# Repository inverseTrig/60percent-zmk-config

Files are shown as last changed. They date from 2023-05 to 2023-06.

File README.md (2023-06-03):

# 60percent

**60percent** (quite original, I know) is a 3D printed, handwired keyboard powered by [ZMK](https://zmk.dev/) inspired by the [tokyo60](https://tokyokeyboard.com/tokyo60/). If you are new to handwiring, [worry not](https://geekhack.org/index.php?topic=87689.0).

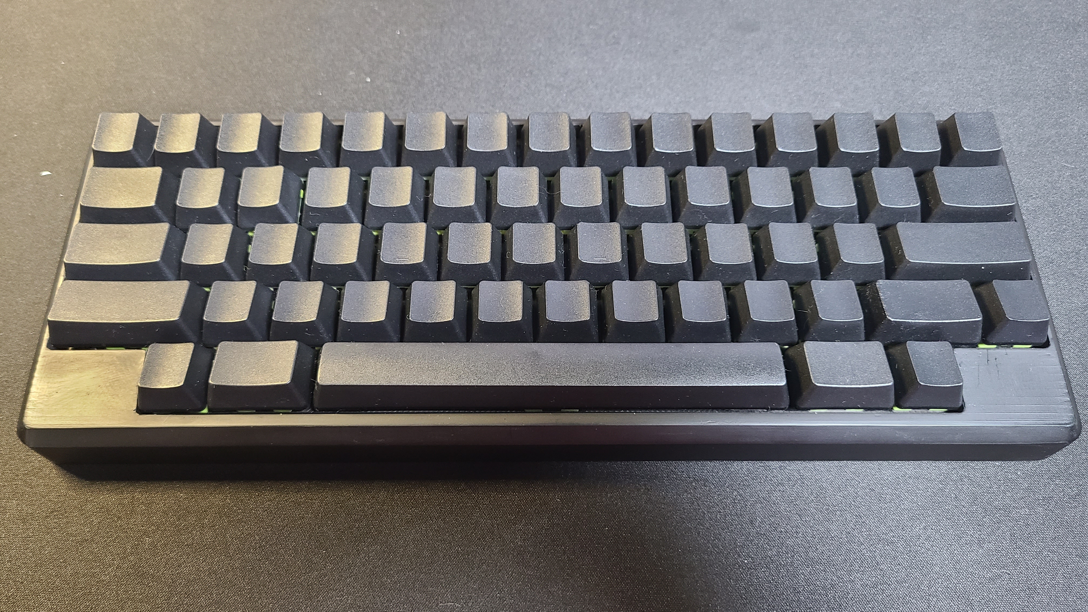
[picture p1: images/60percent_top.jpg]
60percent top

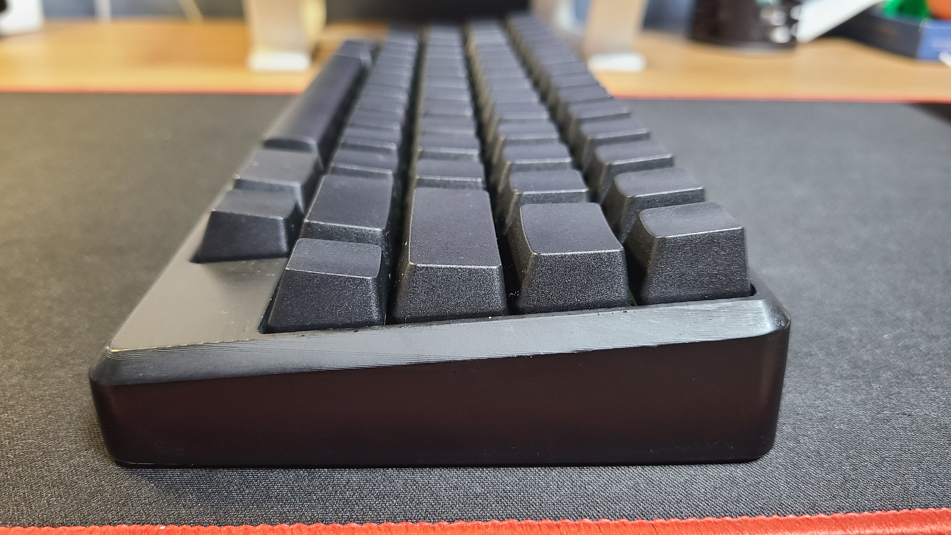
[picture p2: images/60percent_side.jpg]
60percent side

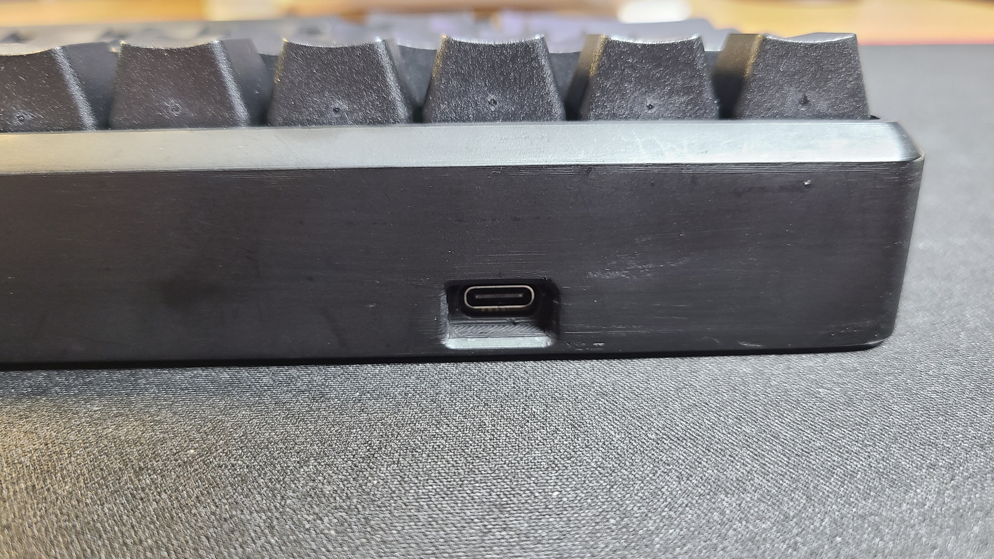
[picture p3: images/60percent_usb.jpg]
60percent USB


## Required Parts

| Part | Qty | Description |
| --- | ----- | --- |
| [Challenger 840 BLE](https://ilabs.se/product/challenger-840-ble/) | 1 | Micro controller board with Bluetooth LE |
| MX-style switches of your choosing | 60 | I used Outemu Lemon/Limes. |
| [1N4148 Diodes](https://a.aliexpress.com/_msALIYo) | 60 | You need these for handwiring |
| [Keycaps](https://a.aliexpress.com/_mt4GitK) | 1 set | You will need a 7u spacebar in the set |
| Cherry [stabilizers](https://a.aliexpress.com/_mOCfD7K) | 1 set | Requires 1 x 7u and 2 x 2u |
| Wires | - | I used wrapping wires |
| [M2 x 6mm hex female-to-female brass standoff (spacer)](https://a.aliexpress.com/_mO2uQEM) | 5 | This is what supports/holds down the plate and the case together |
| M2 x 12mm [countersunk screws](https://a.aliexpress.com/_msph8rW) | 2 | Case-side that goes with the brass standoff |
| M2 x 10mm [countersunk screws](https://a.aliexpress.com/_msph8rW) | 3 | Case-side that goes with the brass standoff |
| M2 x 6mm [flat top screws](https://a.aliexpress.com/_mqwmkN6) | 5 | Plate-side that goes with the brass standoff |
| M2 x 6mm [countersunk screws](https://a.aliexpress.com/_msph8rW) | 4 | Holds the MCU down |
| M2 hex [nut](https://a.aliexpress.com/_m0uPPtO) | 4 | Holds the MCU down |
| 3.7v LiPo Battery | 1 | You'll have to source this locally, as batteries aren't shipped overseas usually |
| [JST 2.0 PH Connector](https://a.aliexpress.com/_mMpUkq8) | 1 | Required if the battery doesn't come with compatible connection |

Note: The countersunk screws are all the same link. The screws, standoff, and the nut are from the same seller. These are all links that I bought from to build my keyboards.

## Diagrams

Below, you can find the rows and columns I wired to the Challenger 840 BLE and the way I wired my columns. I only drew the columns, probably more useful flipped (as the backside of the board is wired), which is also included. I highly encourage you to map your own columns, as I'm worried that it'll be harder to follow mine.
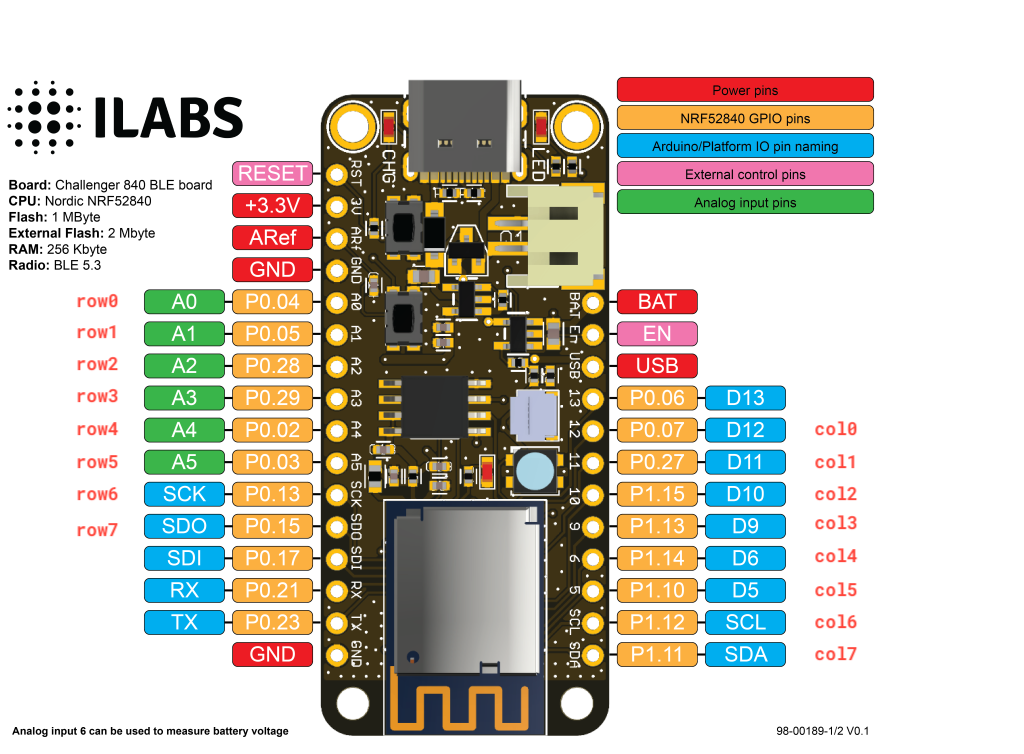
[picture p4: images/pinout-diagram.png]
Pinout diagram

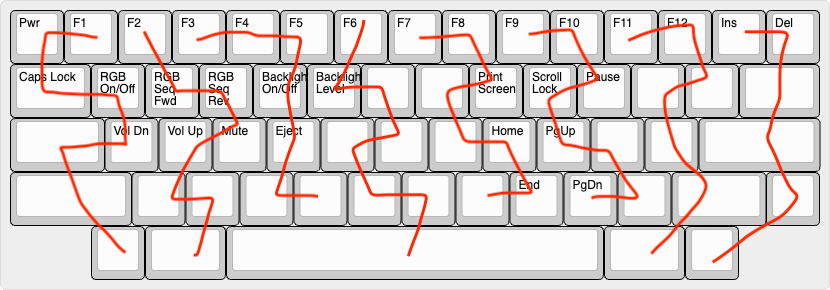
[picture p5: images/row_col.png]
Row column mapping

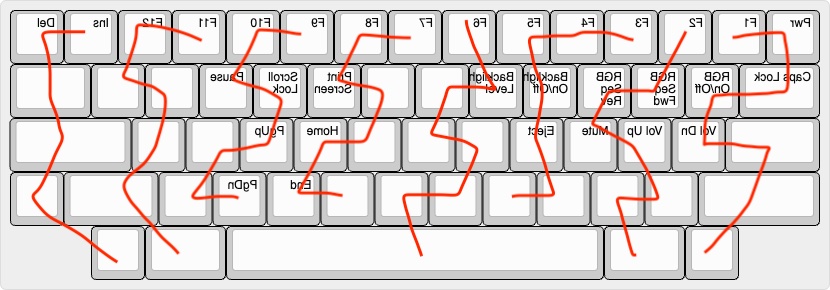
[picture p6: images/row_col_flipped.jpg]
Row column mapping flipped


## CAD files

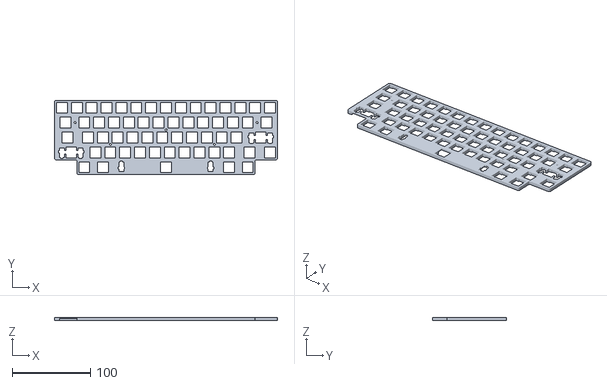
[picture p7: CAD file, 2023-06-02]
things/tokyo60-plate_v3.stl
285.8 x 95.2 x 4.00

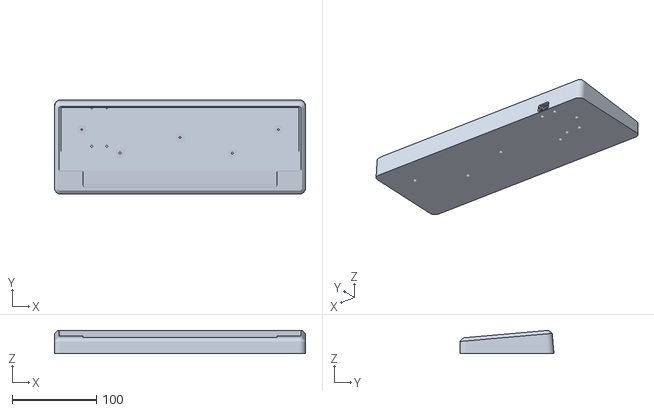
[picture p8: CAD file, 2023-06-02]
things/tokyo60-case_v4.stl
297.8 x 111.5 x 27.7

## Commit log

2023-06-02 feat: add STL
    [tokyo60-case_v4.stl, tokyo60-plate_v3.stl]
2023-06-25 feat: add 한영 key
2023-06-25 feat: add 한자 key
